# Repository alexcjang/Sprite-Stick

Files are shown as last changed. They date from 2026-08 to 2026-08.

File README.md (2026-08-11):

# Sprite-Stick
MicroSD-Driven Mini USB Display Engine built on RP2040 and USB2642

Sprite Stick is an ultra-compact, high-speed custom USB peripheral engineered to dynamically drive a tiny onboard display while serving as a USB mass storage device. Designed as a sleek, self-contained 4-layer PCB, the hardware combines a high-speed USB 2.0 Hub Controller (USB2642), a Waveshare RP2040-Zero micro-controller, a MicroSD card interface, and an integrated SPI display engine.

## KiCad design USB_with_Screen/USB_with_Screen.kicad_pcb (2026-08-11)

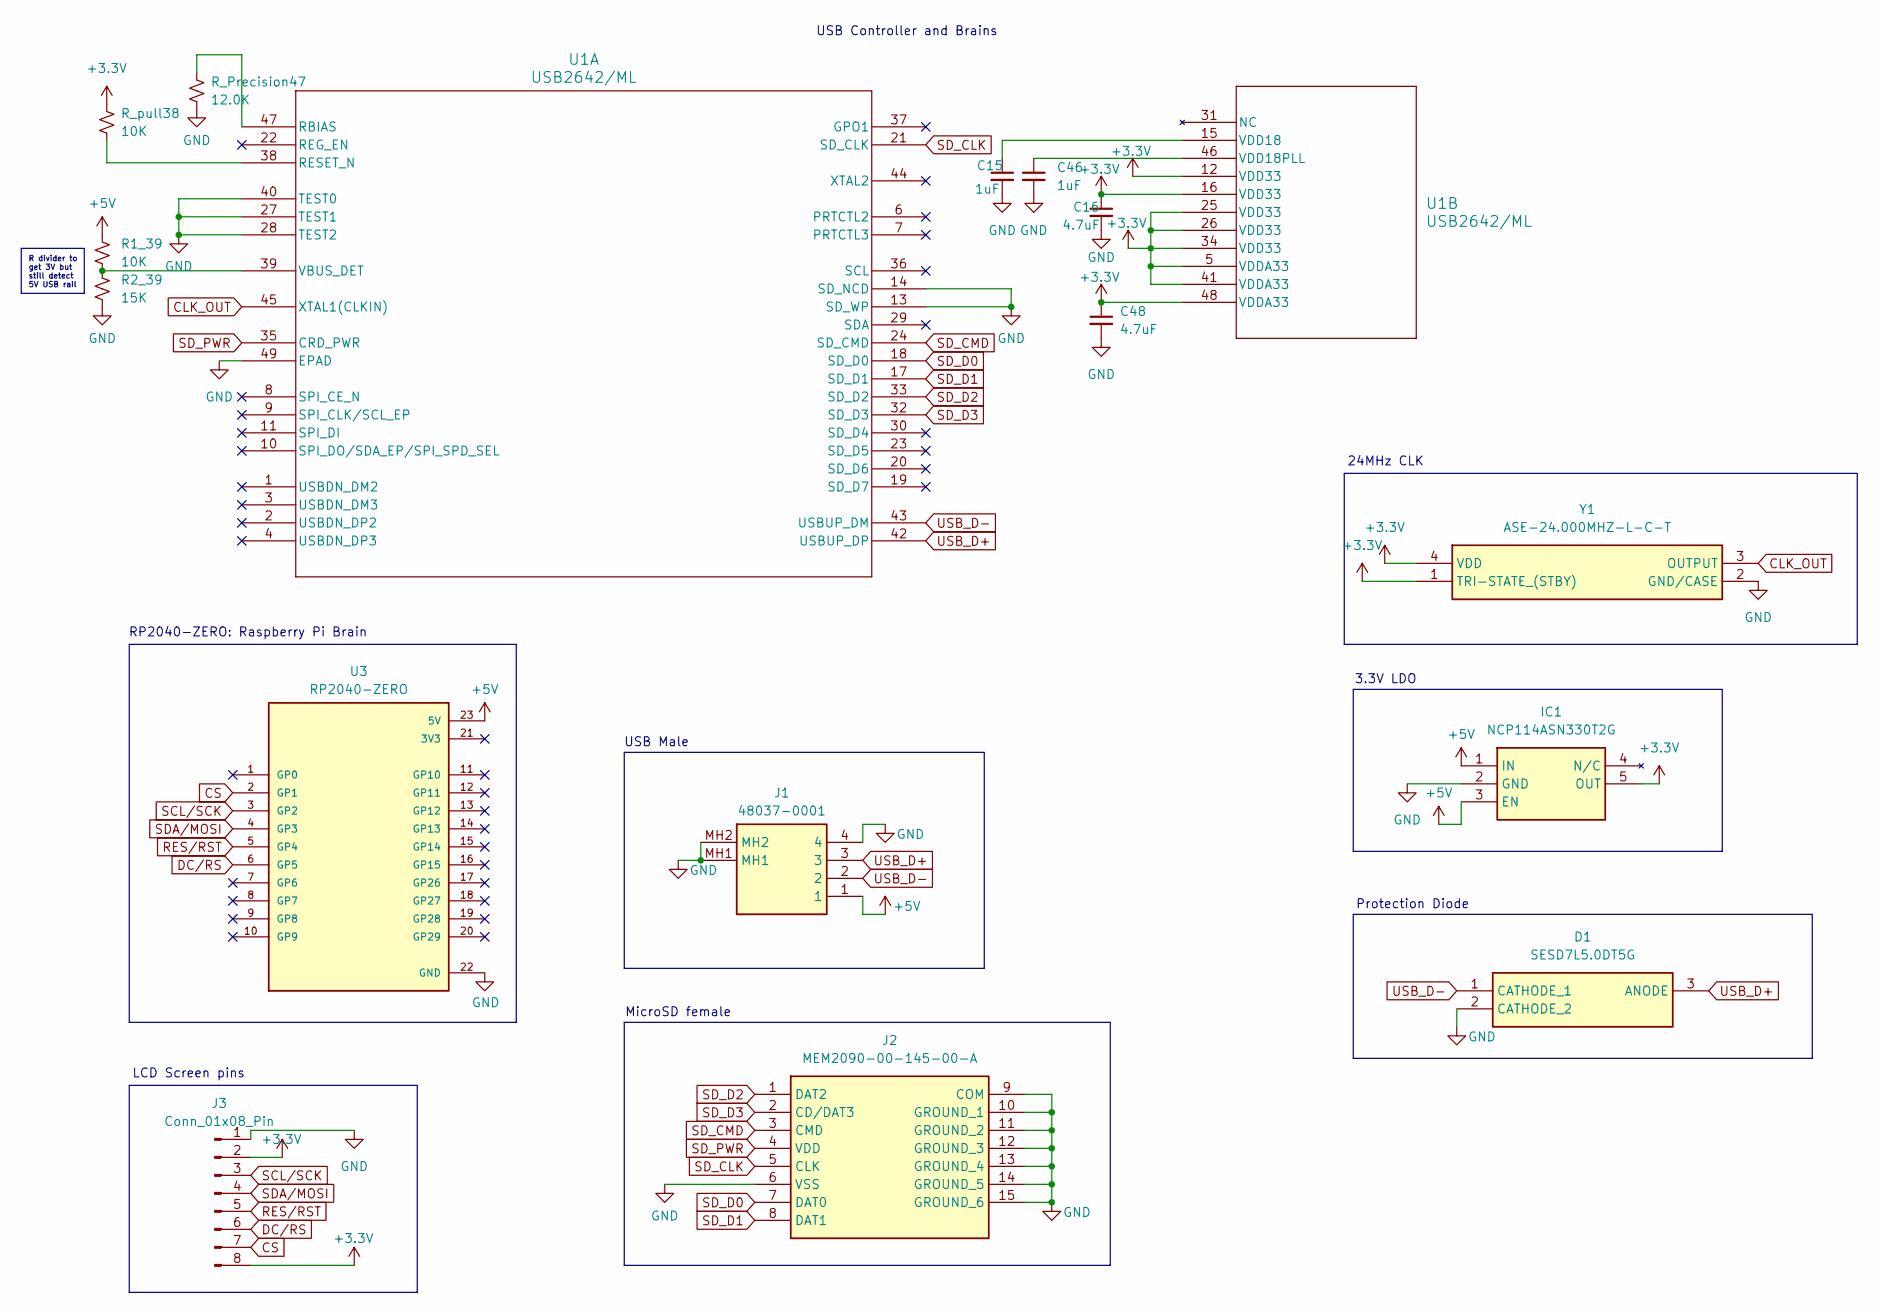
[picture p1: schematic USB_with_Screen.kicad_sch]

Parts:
C15, C46: 1uF; C_0805_2012Metric_Pad1.18x1.45mm_HandSolder
C16, C48: 4.7uF; C_0805_2012Metric_Pad1.18x1.45mm_HandSolder
D1: SESD7L5.0DT5G; SOTFL40P120X55-3N; Mouser Part Number 863-SESD7L5.0DT5G
IC1: NCP114ASN330T2G; SOT95P275X110-5N; Mouser Part Number 863-NCP114ASN330T2G
J1: 48037-0001; 480370001; Mouser Part Number 538-48037-0001
J2: MEM2090-00-145-00-A; MEM20900014500A; Mouser Part Number 640-MEM20900014500A
J3: Conn_01x08_Pin; PinHeader_1x08_P2.54mm_Vertical
R1_39: 10K; R_0805_2012Metric_Pad1.20x1.40mm_HandSolder
R2_39: 15K; R_0805_2012Metric_Pad1.20x1.40mm_HandSolder
R_Precision47: 12.0K; R_0805_2012Metric_Pad1.20x1.40mm_HandSolder
R_pull38: 10K; R_0805_2012Metric_Pad1.20x1.40mm_HandSolder
U1: USB2642/ML; QFN48_7X7MC_MCH
U3: RP2040-ZERO; MODULE_RP2040-ZERO; PARTREV NA
Y1: ASE-24.000MHZ-L-C-T; ASE24576MHZLCT; Mouser Part Number 815-ASE-24.000MLCT

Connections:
+3.3V: C16.1, C48.1, IC1.5 (OUT), J3.2, J3.8, R_pull38.1, U1.5 (VDDA33), U1.12 (VDD33), U1.16 (VDD33), U1.25 (VDD33), U1.26 (VDD33), U1.34 (VDD33), U1.41 (VDDA33), U1.48 (VDDA33), Y1.1 (TRI-STATE_(STBY)), Y1.4 (VDD)
+5V: IC1.1 (IN), IC1.3 (EN), J1.1, R1_39.1, U3.23 (5V)
CLK_OUT: U1.45 (XTAL1(CLKIN)), Y1.3 (OUTPUT)
CS: J3.7, U3.2 (GP1)
DC/RS: J3.6, U3.6 (GP5)
GND: C15.2, C16.2, C46.2, C48.2, D1.2 (CATHODE_2), IC1.2 (GND), J1.4, J1.MH1, J1.MH2, J2.6 (VSS), J2.9 (COM), J2.10 (GROUND_1), J2.11 (GROUND_2), J2.12 (GROUND_3), J2.13 (GROUND_4), J2.14 (GROUND_5), J2.15 (GROUND_6), J3.1, R2_39.2, R_Precision47.2, U1.13 (SD_WP), U1.14 (SD_NCD), U1.27 (TEST1), U1.28 (TEST2), U1.40 (TEST0), U1.49 (EPAD), U3.22 (GND), Y1.2 (GND/CASE)
unnamed: R_Precision47.1, U1.47 (RBIAS)
unnamed: R_pull38.2, U1.38 (RESET_N)
unnamed: R1_39.2, R2_39.1, U1.39 (VBUS_DET)
unnamed: C15.1, U1.15 (VDD18)
unnamed: C46.1, U1.46 (VDD18PLL)
RES/RST: J3.5, U3.5 (GP4)
SCL/SCK: J3.3, U3.3 (GP2)
SDA/MOSI: J3.4, U3.4 (GP3)
SD_CLK: J2.5 (CLK), U1.21 (SD_CLK)
SD_CMD: J2.3 (CMD), U1.24 (SD_CMD)
SD_D0: J2.7 (DAT0), U1.18 (SD_D0)
SD_D1: J2.8 (DAT1), U1.17 (SD_D1)
SD_D2: J2.1 (DAT2), U1.33 (SD_D2)
SD_D3: J2.2 (CD/DAT3), U1.32 (SD_D3)
SD_PWR: J2.4 (VDD), U1.35 (CRD_PWR)
USB_D+: D1.3 (ANODE), J1.3, U1.42 (USBUP_DP)
USB_D-: D1.1 (CATHODE_1), J1.2, U1.43 (USBUP_DM)

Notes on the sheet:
USB Male
LCD Screen pins
Protection Diode
3.3V LDO
USB Controller and Brains
MicroSD female
24MHz CLK
RP2040-ZERO: Raspberry Pi Brain
R divider to get 3V but still detect 5V USB rail

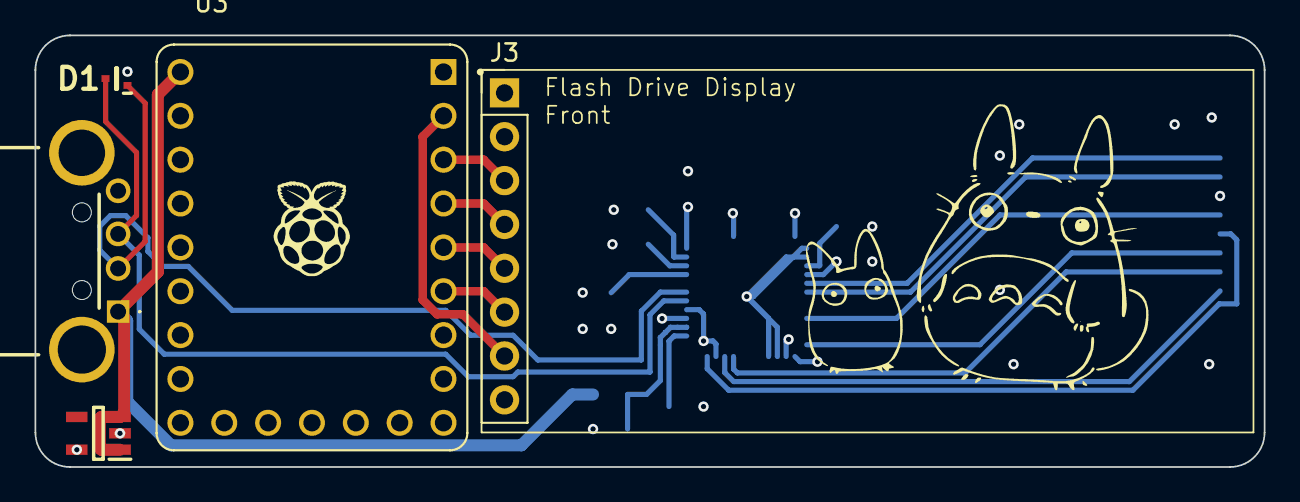
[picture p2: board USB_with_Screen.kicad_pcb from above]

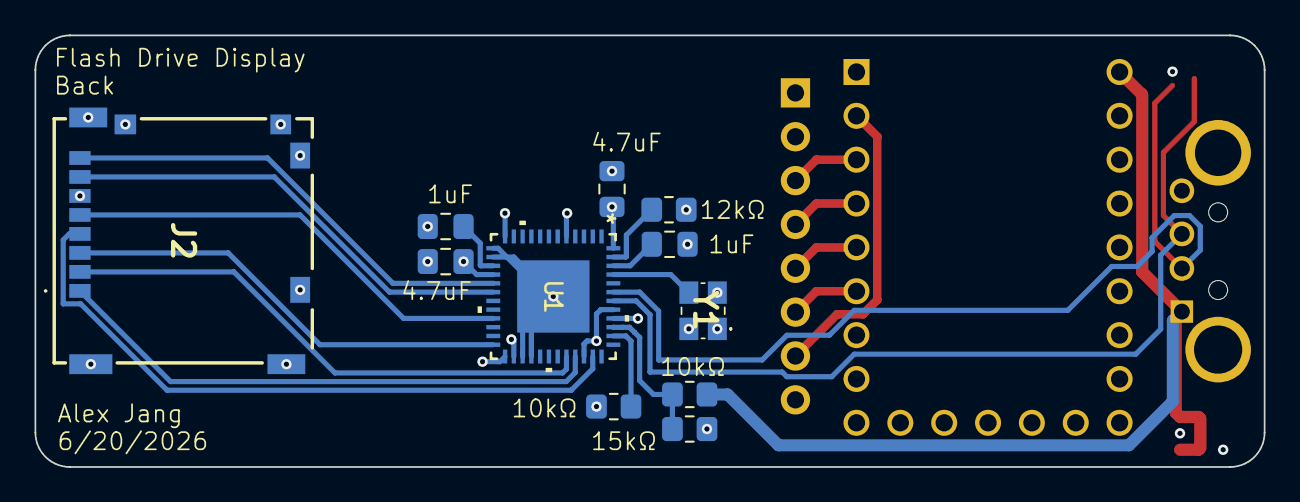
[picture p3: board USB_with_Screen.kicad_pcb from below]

Board: 4 copper layers, 71.2 x 25.0 mm, 16 parts (11 on the bottom side), 23 nets.

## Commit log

2026-08-10 Add initial KiCad schematic and PCB project files
    Includes schematic, pcb, custom extra library files for the components not natively in kicad
    [USB_with_Screen.kicad_pcb, USB_with_Screen.kicad_sch]
2026-08-11 Generated gerber and drill files to order PCB
    [USB_with_Screen-B_Cu.gbl, USB_with_Screen-B_Mask.gbs, USB_with_Screen-B_Paste.gbp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]
2026-08-11 Saved PCB board file after Gerber and Drill file created
    [USB_with_Screen.kicad_pcb]
